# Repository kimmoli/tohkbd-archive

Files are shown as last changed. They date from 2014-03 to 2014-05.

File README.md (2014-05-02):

OBSOLETE
========

This repository is archive only

Please see https://github.com/kimmoli/tohkbd for latest version of daemon.

PCB Files are latest.

STL Files, check dirkvl for possible changes - these are not updated.

tohkbd
======

Jolla TOH keyboard

NEW! RPM installer. <br>
Download tohkbd-<version>.rpm to the phone and install `pkcon install-local tohkbd-<version>.rpm`<br>
Installer will automatically start (and enable autostarting) the tohkbd daemon.

Folder | Waht there?
-------|-------------------------------------
bin    | Executable and rpm<br> Copy file __tohkbd__ to __/home/nemo/test__ folder and give it execute rights (`chmod 755 tohkbd`)<br> Folder can be changed by editing __tohkbd.service__ file
config | System configuration files (systemd) <br> You need root rights to copy these files in place (`devel-su`). <br> __tohkbd.service__ goes to __/etc/systemd/system/__
vkb    | Virtual keyboard to assist external keyboard with clipboard etc. <br> these files goes to __/usr/share/maliit/plugins/com/jolla/layouts/__<br> Note that you might need to restart maliit (not root) `systemctl --user restart maliit-server.service` and possible to check TOHKBD in Settings->Input...
pcb    | Eagle files (Schematic, Board)
stl    | 3D Models for printing
daemon | Sources for daemon. QtCreator project, just build (no deployment)

To get the service started (root) `systemctl start tohkbd.service`

To check is the service running (root) `systemctl status tohkbd.service` and it should say  Active: active (running)

To follow daemon log output `journalctl _SYSTEMD_UNIT=tohkbd.service -f`

*NOTE* <br>If you update binary only, you need to `systemctl stop tohkbd.service` before replacing binary file. <BR>After that you need to start it again with `systemctl start tohkbd.service`

Note that all key presses are logged so take that into account when entering passwords, etc if you also plan to post your device's logfiles to the internet.

More stuff here https://www.dropbox.com/sh/fxocsudk5gd8chs/q587RKRDhk/QWERTY%20OH

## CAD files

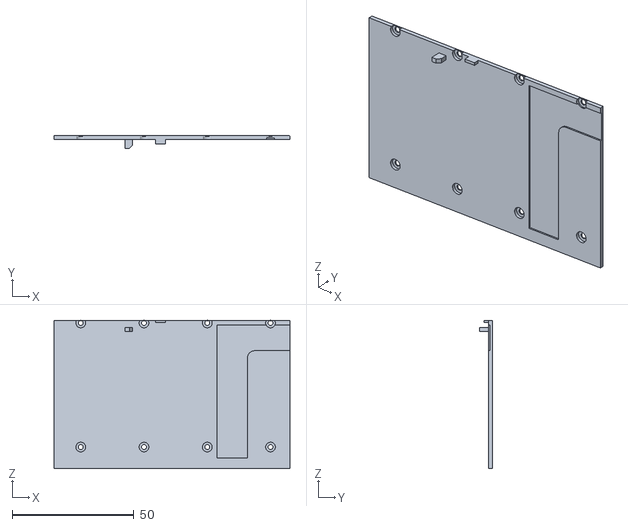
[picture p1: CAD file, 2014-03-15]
stl/Base_insert.STL
97.0 x 5.25 x 61.0

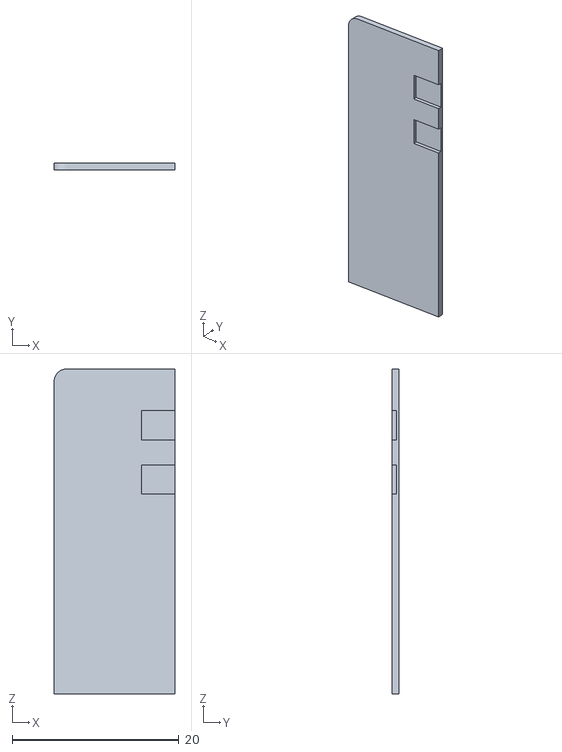
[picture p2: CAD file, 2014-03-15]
stl/Bottom_hatch.STL
14.5 x 0.8 x 39.0

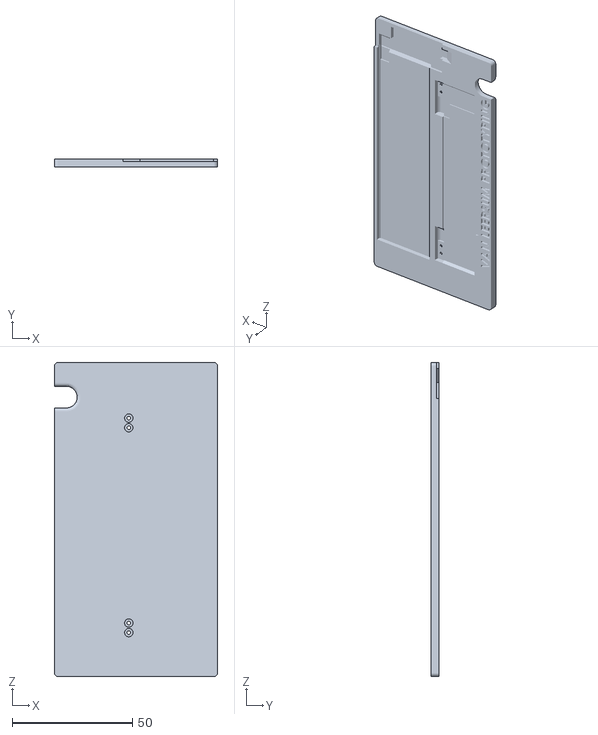
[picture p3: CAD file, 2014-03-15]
stl/Bottom.STL
67.9 x 3.50 x 130.7

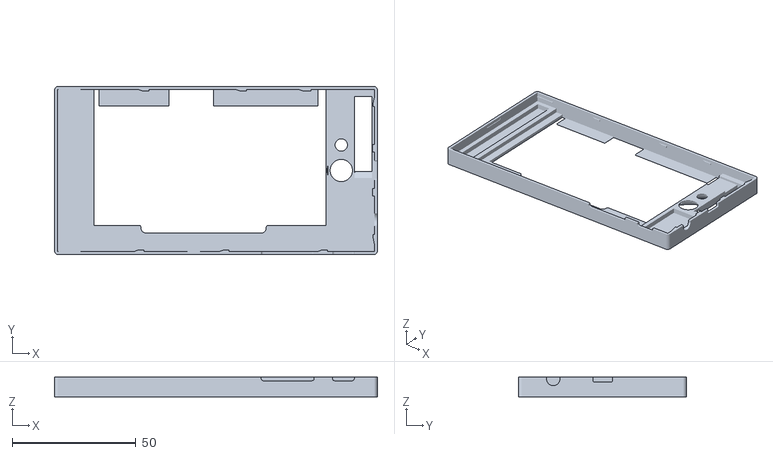
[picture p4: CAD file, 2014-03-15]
stl/Base.STL
130.4 x 67.9 x 8.05

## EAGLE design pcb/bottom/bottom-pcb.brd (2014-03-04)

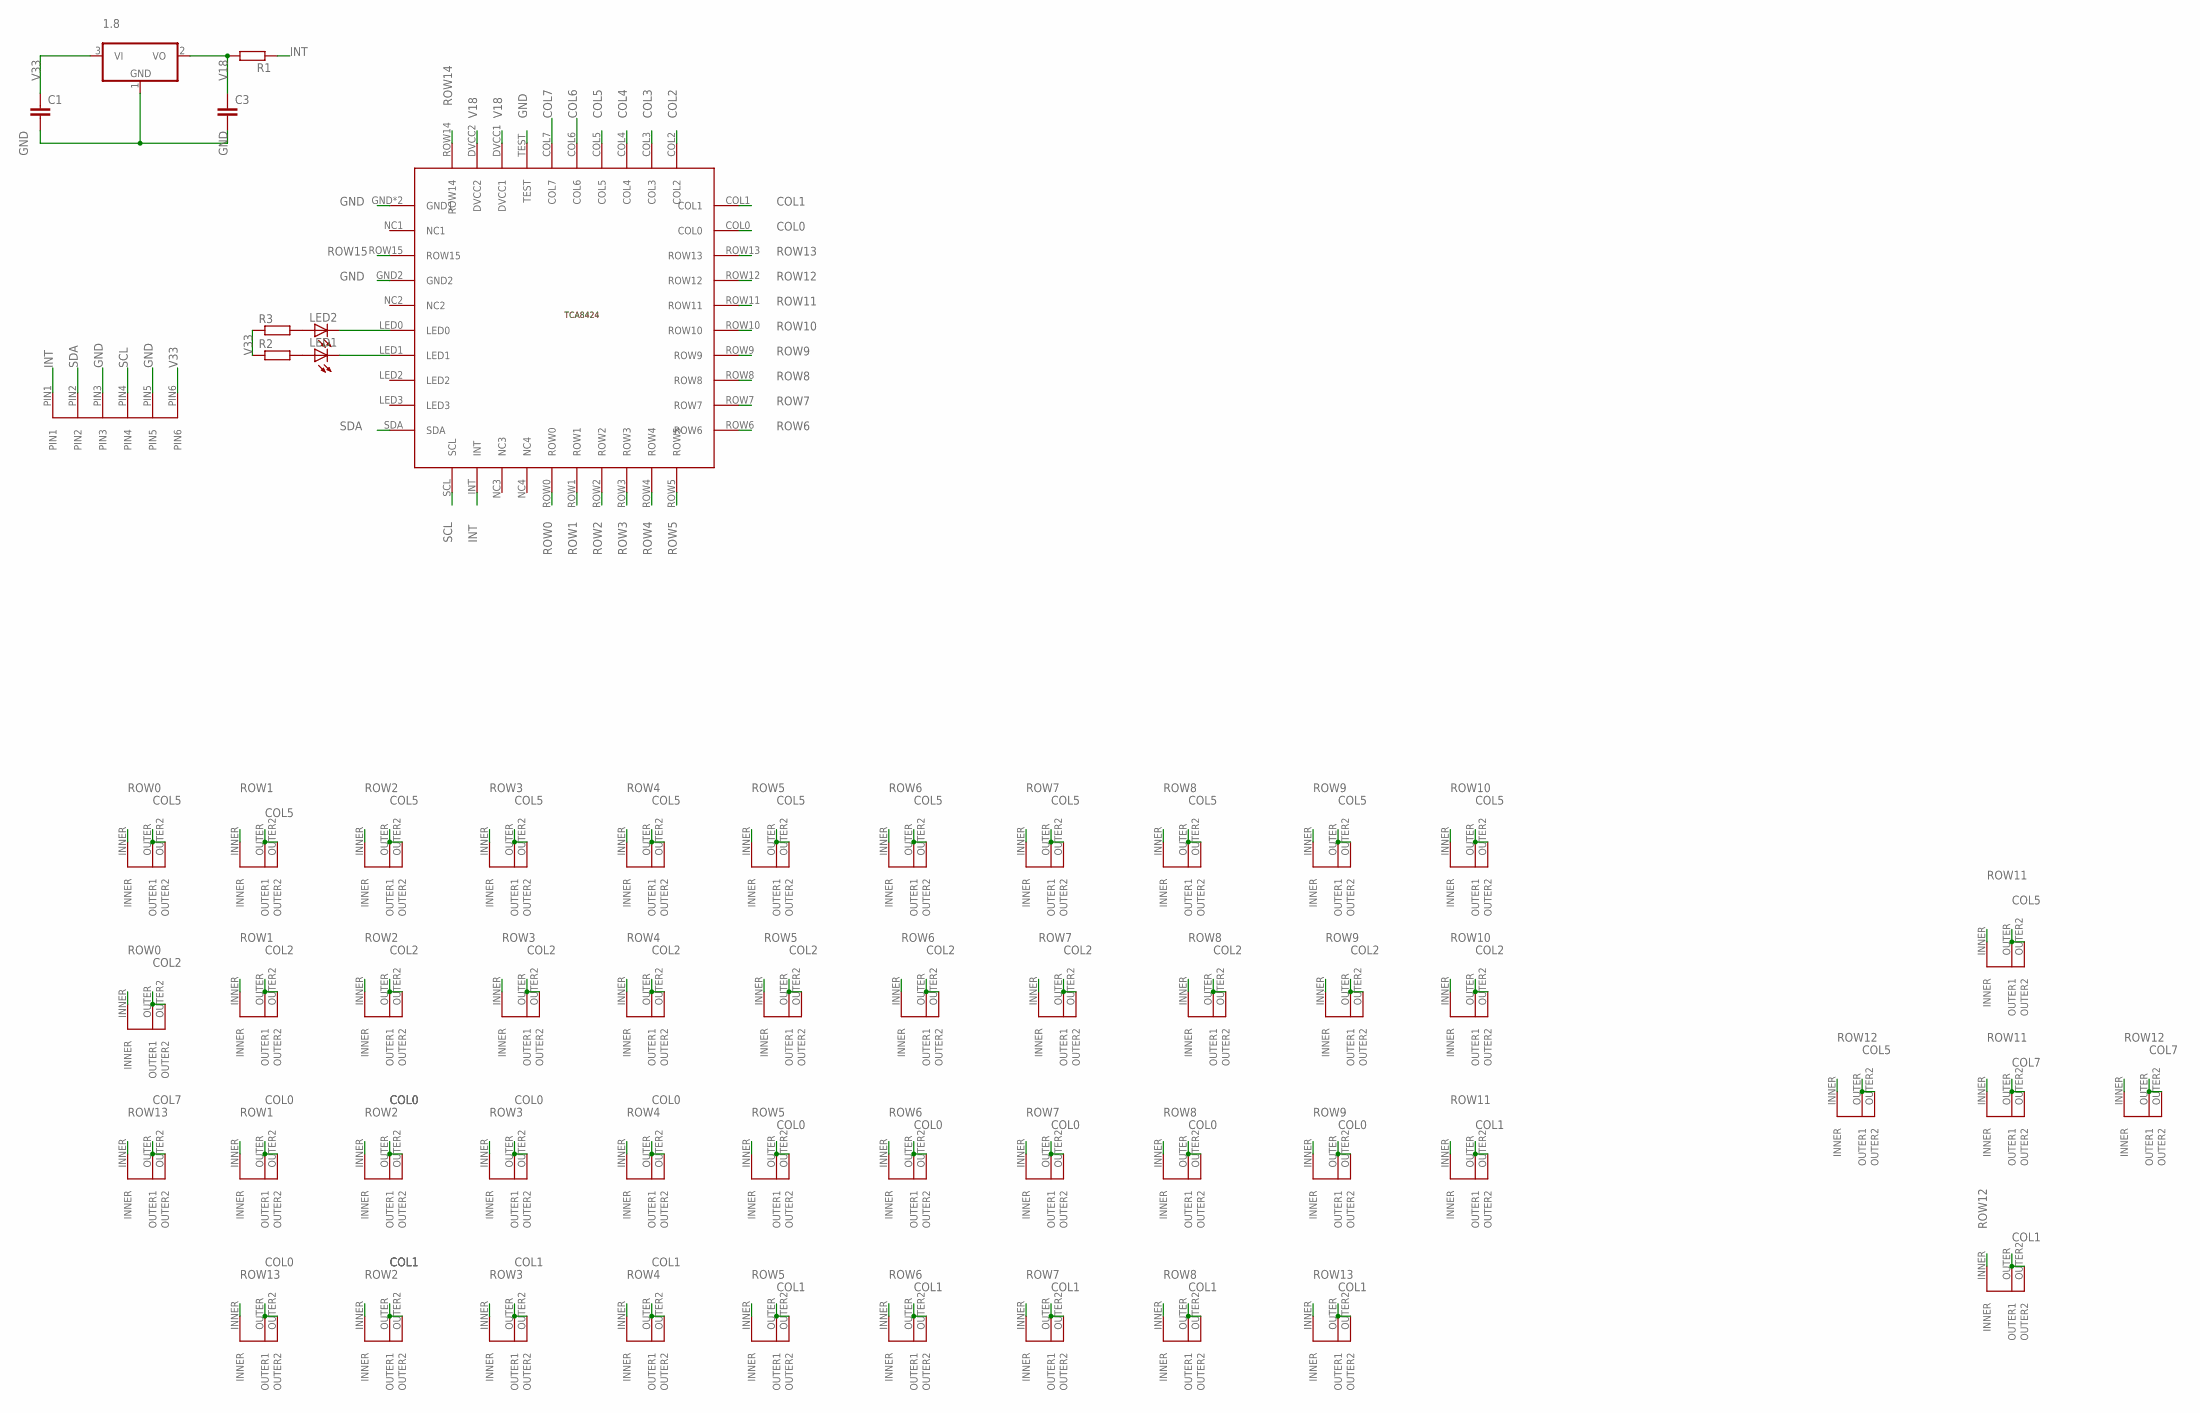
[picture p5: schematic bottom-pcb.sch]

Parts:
1.8: SOT23
?: BUTTON
A: BUTTON
ARROWDOWN: BUTTON
ARROWLEFT: BUTTON
ARROWRIGHT: BUTTON
ARROWUP: BUTTON
AT: BUTTON
B: BUTTON
C: BUTTON
C1, C3: C-EUC0603; C0603
D: BUTTON
DEL: BUTTON
E3: BUTTON
ENTER: BUTTON
F: BUTTON
G: BUTTON
H: BUTTON
I8: BUTTON
J: BUTTON
K: BUTTON
KOMMA: BUTTON
L: BUTTON
LED1, LED2: LEDCHIPLED_0603; CHIPLED_0603
LEFT-ALT: BUTTON
LIST: BUTTON
M: BUTTON
N: BUTTON
O9: BUTTON
OK: BUTTON
P0: BUTTON
PUNT: BUTTON
Q1: BUTTON
R1, R2, R3: R-EU_R0603; R0603
R4: BUTTON
RIGHT-ALT: BUTTON
S: BUTTON
SEARCH: BUTTON
SHIFT, SHIFT2: BUTTON
SLASH: BUTTON
SPACE1, SPACE2, SPACE3: BUTTON
T5: BUTTON
TCA8424-1: QFN40-TCA8424
U7: BUTTON
U$1: 6PCONNECTOR
V: BUTTON
W2: BUTTON
X: BUTTON
Y6: BUTTON
Z: BUTTON

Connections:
COL0: B.OUTER (OUTER1), B.OUTER2, C.OUTER (OUTER1), C.OUTER2, KOMMA.OUTER (OUTER1), KOMMA.OUTER2, LEFT-ALT.OUTER (OUTER1), LEFT-ALT.OUTER2, M.OUTER (OUTER1), M.OUTER2, N.OUTER (OUTER1), N.OUTER2, PUNT.OUTER (OUTER1), PUNT.OUTER2, TCA8424-1.COL0, V.OUTER (OUTER1), V.OUTER2, X.OUTER (OUTER1), X.OUTER2, Z.OUTER (OUTER1), Z.OUTER2
COL1: ARROWDOWN.OUTER (OUTER1), ARROWDOWN.OUTER2, AT.OUTER (OUTER1), AT.OUTER2, LIST.OUTER (OUTER1), LIST.OUTER2, RIGHT-ALT.OUTER (OUTER1), RIGHT-ALT.OUTER2, SEARCH.OUTER (OUTER1), SEARCH.OUTER2, SHIFT2.OUTER (OUTER1), SHIFT2.OUTER2, SLASH.OUTER (OUTER1), SLASH.OUTER2, SPACE1.OUTER (OUTER1), SPACE1.OUTER2, SPACE2.OUTER (OUTER1), SPACE2.OUTER2, SPACE3.OUTER (OUTER1), SPACE3.OUTER2, TCA8424-1.COL1
COL2: ?.OUTER (OUTER1), ?.OUTER2, A.OUTER (OUTER1), A.OUTER2, D.OUTER (OUTER1), D.OUTER2, ENTER.OUTER (OUTER1), ENTER.OUTER2, F.OUTER (OUTER1), F.OUTER2, G.OUTER (OUTER1), G.OUTER2, H.OUTER (OUTER1), H.OUTER2, J.OUTER (OUTER1), J.OUTER2, K.OUTER (OUTER1), K.OUTER2, L.OUTER (OUTER1), L.OUTER2, S.OUTER (OUTER1), S.OUTER2, TCA8424-1.COL2
COL3: TCA8424-1.COL3
COL4: TCA8424-1.COL4
COL5: ARROWLEFT.OUTER (OUTER1), ARROWLEFT.OUTER2, ARROWUP.OUTER (OUTER1), ARROWUP.OUTER2, DEL.OUTER (OUTER1), DEL.OUTER2, E3.OUTER (OUTER1), E3.OUTER2, I8.OUTER (OUTER1), I8.OUTER2, O9.OUTER (OUTER1), O9.OUTER2, P0.OUTER (OUTER1), P0.OUTER2, Q1.OUTER (OUTER1), Q1.OUTER2, R4.OUTER (OUTER1), R4.OUTER2, T5.OUTER (OUTER1), T5.OUTER2, TCA8424-1.COL5, U7.OUTER (OUTER1), U7.OUTER2, W2.OUTER (OUTER1), W2.OUTER2, Y6.OUTER (OUTER1), Y6.OUTER2
COL6: TCA8424-1.COL6
COL7: ARROWRIGHT.OUTER (OUTER1), ARROWRIGHT.OUTER2, OK.OUTER (OUTER1), OK.OUTER2, SHIFT.OUTER (OUTER1), SHIFT.OUTER2, TCA8424-1.COL7
GND: 1.8.1 (GND), C1.2, C3.2, TCA8424-1.GND (GND1), TCA8424-1.GND1, TCA8424-1.GND2, TCA8424-1.TEST, U$1.PIN3, U$1.PIN5
INT: R1.1, TCA8424-1.INT, U$1.PIN1
unnamed: LED1.C, TCA8424-1.LED1
unnamed: LED2.C, TCA8424-1.LED0
unnamed: LED1.A, R2.2
unnamed: LED2.A, R3.2
ROW0: A.INNER, Q1.INNER, TCA8424-1.ROW0
ROW1: S.INNER, TCA8424-1.ROW1, W2.INNER, Z.INNER
ROW2: D.INNER, E3.INNER, SEARCH.INNER, TCA8424-1.ROW2, X.INNER
ROW3: AT.INNER, C.INNER, F.INNER, R4.INNER, TCA8424-1.ROW3
ROW4: G.INNER, SPACE1.INNER, T5.INNER, TCA8424-1.ROW4, V.INNER
ROW5: B.INNER, H.INNER, SPACE2.INNER, TCA8424-1.ROW5, Y6.INNER
ROW6: J.INNER, N.INNER, SPACE3.INNER, TCA8424-1.ROW6, U7.INNER
ROW7: I8.INNER, K.INNER, M.INNER, SLASH.INNER, TCA8424-1.ROW7
ROW8: KOMMA.INNER, L.INNER, LIST.INNER, O9.INNER, TCA8424-1.ROW8
ROW9: ?.INNER, P0.INNER, PUNT.INNER, TCA8424-1.ROW9
ROW10: DEL.INNER, ENTER.INNER, TCA8424-1.ROW10
ROW11: ARROWUP.INNER, OK.INNER, SHIFT2.INNER, TCA8424-1.ROW11
ROW12: ARROWDOWN.INNER, ARROWLEFT.INNER, ARROWRIGHT.INNER, TCA8424-1.ROW12
ROW13: LEFT-ALT.INNER, RIGHT-ALT.INNER, SHIFT.INNER, TCA8424-1.ROW13
ROW14: TCA8424-1.ROW14
ROW15: TCA8424-1.ROW15
SCL: TCA8424-1.SCL, U$1.PIN4
SDA: TCA8424-1.SDA, U$1.PIN2
V18: 1.8.2 (VO), C3.1, R1.2, TCA8424-1.DVCC1, TCA8424-1.DVCC2
V33: 1.8.3 (VI), C1.1, R2.1, R3.1, U$1.PIN6

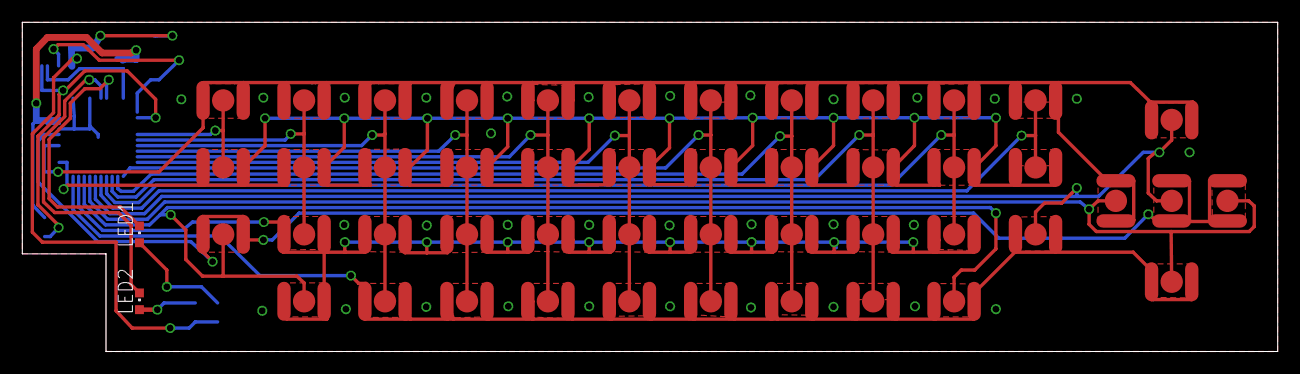
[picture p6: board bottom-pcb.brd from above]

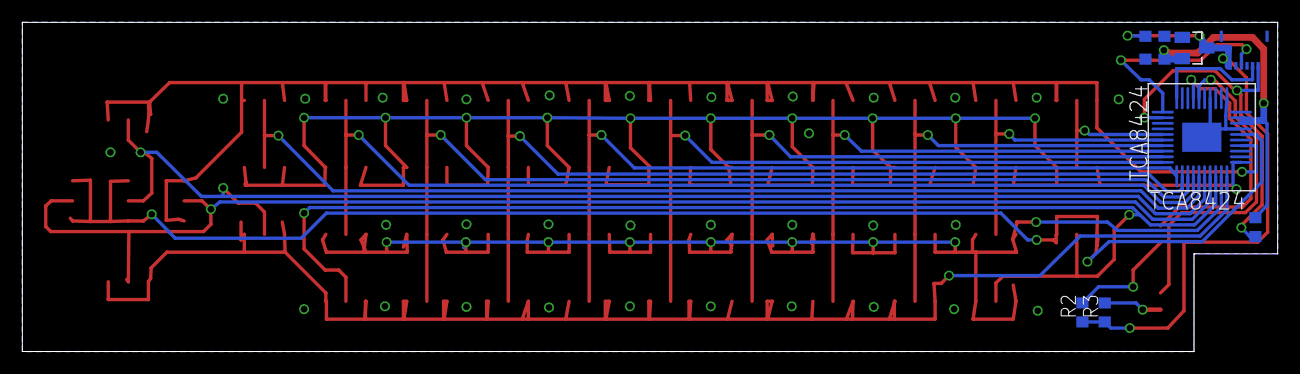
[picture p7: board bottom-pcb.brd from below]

Board: 4 copper layers, 112.5 x 29.5 mm, 57 parts (8 on the bottom side), 29 nets.

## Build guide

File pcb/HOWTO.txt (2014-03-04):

1. Download and install Cadsoft Eagle (there is a free version)
2. Download the files
3. Watch this tutorial and do the exercizes to become an instant pro: https://www.youtube.com/playlist?list=PLB4C63828A483E756
4. Open the .brd files and watch/edit/whatever as much as you can
5. Start your own project and be awesome! It's easier than you think!

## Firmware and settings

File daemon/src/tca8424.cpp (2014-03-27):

/*
 * (C) 2014 Kimmo Lindholm <kimmo.lindholm@gmail.com> Kimmoli
 *
 * Routines for TCA8424
 *
 *
 *
 *
 */

#include <fcntl.h>
#include <stdio.h>
#include <string.h>
#include <unistd.h>
#include <linux/i2c-dev.h>
#include <linux/input.h>
#include <sys/ioctl.h>
#include "tca8424.h"


int tca8424_reset(int file)
{
    const unsigned char buf[4] = {0x00, 0x06, 0x00, 0x01};
    if (write(file, buf, sizeof(buf)) != sizeof(buf))
    {
        printf("tca8424: failed to reset\n");
        return -1;
    }
    return 0;
}

int tca8424_leds(int file, unsigned char leds)
{
    unsigned char buf[9] = {0x00, 0x06, 0x20, 0x03, 0x00, 0x07, 0x01, 0x00, leds};
    if (write(file, buf, sizeof(buf)) != sizeof(buf))
    {
        printf("tca8424: failed to set led state\n");
        return -1;
    }
    return 0;
}


int tca8424_initComms(unsigned char addr)
{
    int file;

    /* open file and start ioctl */
    if ((file = open("/dev/i2c-1", O_RDWR)) < 0)
    {
        printf("tca8424: failed to open /dev/i2c-1\n");
        return -1;
    }
    if (ioctl(file, I2C_SLAVE, addr) < 0)
    {
        printf("tca8424: failed to ioctl(/dev/i2c-1, I2C_SLAVE, 0x%x)\n",
               (unsigned int) addr);
        close(file);
        return -1;
    }
    return file;
}

int tca8424_closeComms(int file)
{
    close(file);
    return 0;
}

int tca8424_readInputReport(int file, char* report)
{
    const unsigned char buf[6] = {0x00, 0x06, 0x11, 0x02, 0x00, 0x07};

    if (write(file, buf, sizeof(buf)) != sizeof(buf))
    {
        printf("tca8424: failed to request input report\n");
        return -1;
    }

    memset(report, 0, 12);
    if (read(file, report, 11) != 11)
    {
        printf("tca8424: failed to read input report\n");
        return -1;
    }

    return 0;
}

int tca8424_readMemory(int file, int start, int len, char* data)
{
    unsigned char buf[2] =
        {(unsigned char) (start & 0xff), (unsigned char) ((start>>8) & 0xff)};

    if (write(file, buf, sizeof(buf)) != sizeof(buf))
    {
        printf("tca8424: failed to request memory\n");
        return -1;
    }

    if (read(file, data, len) != len)
    {
        printf("tca8424: failed to read memory\n");
        return -1;
    }

    return 0;
}

/*
 *
 * dat Horrible key-press decoder
 *
 */

const char* tca8424_processKeyMap(char *input, int *c, int *shift, int *alt, int *ctrl)
{
    unsigned char k = input[5];

    *c = 0;
    *shift = false;
    *alt = false;
    *ctrl = false;

    /* first check for shift, alt and ctrl */
    if (k == 0x9E || k == 0xBC)
    {
        *shift = true;
    }
    else if (k == 0xAE || k == 0xBE)
    {
        *alt = true;
    }
    else if (k == 0xB3)
    {
        *ctrl = true;
        return "! Ctrl";
    }

    /* if alt, use alternate key mapping */
    if (*alt)
    {
        k = input[6];
        if (k == 0xC1) { *c = KEY_TAB; return "A Tab"; }
        if (k == 0xF1) { *c = KEY_1; return "Q 1"; }
        if (k == 0xA2) { *c = KEY_COMMA; *shift = true; return "Z <"; }
        if (k == 0xC2) { *c = KEY_1; *shift = true; return "S !"; }
        if (k == 0xF2) { *c = KEY_2; return "W 2"; }
        if (k == 0xA3) { *c = KEY_DOT; *shift = true; return "X >"; }
        if (k == 0xC3) { *c = KEY_3; *shift = true; return "D #"; }
        if (k == 0xF3) { *c = KEY_3; return "E 3"; }
        if (k == 0xA4) { *c = KEY_MINUS; *shift = true; return "C _"; }
        if (k == 0xC4) { *c = KEY_4; *shift = true; return "F $"; }
        if (k == 0xF4) { *c = KEY_4; return "R 4"; }
        if (k == 0xA5) { *c = KEY_MINUS; return "V -"; }
        if (k == 0xC5) { *c = KEY_5; *shift = true; return "G %"; }
        if (k == 0xF5) { *c = KEY_5; return "T 5"; }
        if (k == 0xA6) { *c = KEY_KPPLUS; return "B +"; }
        if (k == 0xC6) { *c = KEY_EQUAL; return "H ="; }
        if (k == 0xF6) { *c = KEY_6; return "Y 6"; }
        if (k == 0xA7) { *c = KEY_APOSTROPHE; *shift = true; return "N """; }
        if (k == 0xC7) { *c = KEY_7; *shift = true; return "J &"; }
        if (k == 0xF7) { *c = KEY_7; return "U 7"; }
        if (k == 0xA8) { *c = KEY_APOSTROPHE; return "M '"; }
        if (k == 0xC8) { *c = KEY_8; *shift = true; return "K *"; }
        if (k == 0xF8) { *c = KEY_8; return "I 8"; }
        if (k == 0xC9) { *c = KEY_9; *shift = true; return "L ("; }
        if (k == 0xF9) { *c = KEY_9; return "O 9"; }
        if (k == 0xAA) { *c = KEY_SEMICOLON; *shift = true; return ". :"; }
        if (k == 0xA9) { *c = KEY_SEMICOLON; return ", ;"; }
        if (k == 0xCA) { *c = KEY_0; *shift = true; return "? )"; }
        if (k == 0xFA) { *c = KEY_0; return "P 0"; }
        if (k == 0xB4) { *c = KEY_GRAVE; *shift = true; return "@ ~"; }
        if (k == 0xB8) { *c = KEY_6; *shift = true; return "/ ^"; }
        if (k == 0xFD) { *c = KEY_HOME; return "Left Arrow"; }
        if (k == 0x9D) { *c = KEY_END; return "Right Arrow"; }
        if (k == 0xFC) { *c = KEY_PAGEUP; *shift = true; return "Up arrow"; }
        if (k == 0xBD) { *c = KEY_PAGEDOWN; *shift = true; return "Down arrow"; }
        if (k == 0xB9) { *c = KEY_ESC; return "| Escape"; }

        if (k == 0x00) return "! Released";

        return "* Unknown";
    }

    /* if shift, check the next key in map */
    if (*shift)
        k = input[6];
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

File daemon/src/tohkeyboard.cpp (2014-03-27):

/*
 * (C) 2014 Kimmo Lindholm <kimmo.lindholm@gmail.com> Kimmoli
 *
 * tohkbd daemon, d-bus server call method functions.
 *
 */


#include <QtCore/QCoreApplication>
#include <QDBusMessage>
#include <QThread>

#include <unistd.h>
#include <linux/input.h>
#include <linux/uinput.h>

#include "tohkeyboard.h"
#include "toh.h"
#include "tca8424.h"
#include "uinputif.h"


bool Tohkbd::interruptsEnabled = false;
bool Tohkbd::vddEnabled = false;

int Tohkbd::capsLockSeq = 0;

/* Main */
Tohkbd::Tohkbd()
{
    thread = new QThread();
    worker = new Worker();

    worker->moveToThread(thread);
    connect(worker, SIGNAL(gpioInterruptCaptured()), this, SLOT(handleGpioInterrupt()));
    connect(worker, SIGNAL(workRequested()), thread, SLOT(start()));
    connect(thread, SIGNAL(started()), worker, SLOT(doWork()));
    connect(worker, SIGNAL(finished()), thread, SLOT(quit()), Qt::DirectConnection);

    /* do this automatically at startup */
    setVddState(true);
    setInterruptEnable(true);

    uinputif = new UinputIf();
    uinputif->openUinputDevice();
}


/* Function to set VDD (3.3V for OH) */
bool Tohkbd::setVddState(bool state)
{
    printf("VDD control request - turn %s\n", state ? "on" : "off");

    if (vddEnabled == state)
    {
        printf("VDD state already %s\n", state ? "on" : "off");
    }
    else if (controlVdd(state) < 0)
    {
        vddEnabled = false;
        printf("VDD control FAILED\n");
    }
    else
    {
        vddEnabled = state;
        printf("VDD control OK\n");
    }

    return vddEnabled;
}


/*
 *    Interrupt stuff
 */


bool Tohkbd::setInterruptEnable(bool state)
{
    printf("Interrupt control request - turn %s\n", state ? "on" : "off");

    if (!vddEnabled)
    {
        printf("Interrupt requested but VDD Not active. Aborting.\n");
        return false;
    }
    else if (state == interruptsEnabled)
    {
        printf("Interrupt state already %s\n", state ? "on" : "off");
        return interruptsEnabled;
    }

    worker->abort();
    thread->wait(); // If the thread is not running, this will immediately return.
    interruptsEnabled = false;
    if (gpio_fd >= 0)
    {
        releaseTohInterrupt(gpio_fd);
        gpio_fd = -1;
    }

    if (state)
    {
        gpio_fd = getTohInterrupt();
        if (gpio_fd < 0)
        {
            printf("failed to enable interrupt (are you root?)\n");
        }
        else
        {
            int fd = tca8424_initComms(TCA_ADDR);
            if (fd < 0)
            {
                printf("failed to start communication with TCA8424\n");
                releaseTohInterrupt(gpio_fd);
                gpio_fd = -1;
            }
            else
            {
                tca8424_reset(fd);
                tca8424_closeComms(fd);

                worker->requestWork(gpio_fd);
                printf("worker started\n");

                interruptsEnabled = true;
            }
        }
    }

    return interruptsEnabled;
}

void Tohkbd::handleDisplayStatus(const QDBusMessage& msg)
{
    QList<QVariant> args = msg.arguments();
    const char *turn = qPrintable(args.at(0).toString());

    printf("Display status changed to \"%s\"\n", turn);
    if (strcmp(turn, "on") == 0)
    {
        printf("enabling tohkbd\n");
        setVddState(true);
        setInterruptEnable(true);
    }
    else if (strcmp(turn, "off") == 0)
    {
        printf("disabling tohkbd\n");
        setInterruptEnable(false);
        setVddState(false);
    }
}



/*
 *  GPIO interrupt handler
 *
 */

void Tohkbd::handleGpioInterrupt()
{
    static int haveCtrl = 0;
    int fd, code, isShift, isAlt, isCtrl;
    char inRep[12];
    const char *buf;

    mutex.lock();

    fd = tca8424_initComms(TCA_ADDR);
    if (fd < 0)
    {
        printf("failed to start communication with TCA8424\n");
        mutex.unlock();
        return;
    }
    tca8424_readInputReport(fd, inRep);

    buf = tca8424_processKeyMap(inRep, &code, &isShift, &isAlt, &isCtrl);

    if ((code != 0) && (capsLockSeq == 1 || capsLockSeq == 2)) /* Abort caps-lock if other key pressed */
        capsLockSeq = 0;

    if (code == 0 && isShift && capsLockSeq == 0) /* Shift pressed first time */
        capsLockSeq = 1;
    else if (code == 0 && buf[0]=='!' && capsLockSeq == 1) /* Shift released */
        capsLockSeq = 2;
    else if (code == 0 && isShift && capsLockSeq == 2) /* Shift pressed 2nd time */
    {
        capsLockSeq = 3;
        uinputif->sendUinputKeyPress(KEY_CAPSLOCK, 1);
        uinputif->sendUinputKeyPress(KEY_CAPSLOCK, 0);
        uinputif->synUinputDevice();
        tca8424_leds(fd, 1);
        printf("CapsLock on\n");
    }
    else if (code == 0 && isShift && capsLockSeq == 3) /* Shift pressed 3rd time */
    {
        capsLockSeq = 0;
        uinputif->sendUinputKeyPress(KEY_CAPSLOCK, 1);
        uinputif->sendUinputKeyPress(KEY_CAPSLOCK, 0);
        uinputif->synUinputDevice();
        tca8424_leds(fd, 0);
        printf("CapsLock off\n");
    }
    else if (code == 0 && isCtrl) /* Ctrl pressed */
    {
        haveCtrl ^= 1;
        uinputif->sendUinputKeyPress(KEY_LEFTCTRL, haveCtrl);
        printf("%s\n", haveCtrl ? "Ctrl down" : "Ctrl lifted");
    }

    if (code != 0) /* We resolved what was pressed */
    {
        printf("Key pressed: %s (%d 0x%02x shft=%d alt=%d ctrl=%d)\n",
               buf, code, inRep[5], isShift, isAlt, haveCtrl);

        if (isShift)
            uinputif->sendUinputKeyPress(KEY_LEFTSHIFT, 1);
        uinputif->sendUinputKeyPress(code, 1);
        uinputif->sendUinputKeyPress(code, 0);
        if (isShift)
            uinputif->sendUinputKeyPress(KEY_LEFTSHIFT, 0);
        if (haveCtrl)
        {
            uinputif->sendUinputKeyPress(KEY_LEFTCTRL, 0);
            printf("Ctrl released automatically\n");
            haveCtrl = 0;
        }

        uinputif->synUinputDevice();

    }
    else if (buf[0] != '!')
    {
        printf("UNK Input report: %s %02x%02x%02x%02x%02x %02x%02x%02x%02x%02x%02x\n",
               buf, inRep[0], inRep[1], inRep[2], inRep[3], inRep[4], inRep[5],
               inRep[6], inRep[7], inRep[8], inRep[9], inRep[10]);
    }

    tca8424_closeComms(fd);
    mutex.unlock();
}

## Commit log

2014-03-04 Original PCB Files added
    [base-pcb.brd, base-pcb.sch, bottom-pcb.brd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]
2014-03-15 stl files added
    [Base.STL, Base_insert.STL, Bottom.STL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]
2014-03-20 daemon: replace custom writeToLog with printing to stdout
    systemd automatically forwards process stdout and stderr to the journal
    where it can be viewed. make sure to set stdout and stderr to linebuffered
    mode so the journal events are not delayed.
    [tohkeyboard.cpp]
2014-03-21 tca8424: fix tab, question mark and caret characters
    [tca8424.cpp]
2014-03-21 tohkeyboard: disable leds by default
2014-03-21 tohkeyboard: capslock enables led
2014-03-21 tohkeyboard: free mutex if reading keyboard fails
    [tohkeyboard.cpp]
2014-03-23 Update tca8424.cpp, Right control as backslash/pipe/ESC
    This way both missing keys are covered and ESC is still usable
    [tca8424.cpp]
2014-03-23 Fix for PageUp/PageDown
    Works in midnight commander and nano this way, not sure if proper fix
    [tca8424.cpp]
2014-03-25 daemon: cleanups to output error messages and silence compiler warnings
    * make sure to print an error message when opening, reading or writing to
    various files/devices fails
    * more updates for more consistent indentation and code style
    * use booleans instead of strings as arguments to internal functions
    * clean up unused includes and code
    [tca8424.cpp, tohkeyboard.cpp]
